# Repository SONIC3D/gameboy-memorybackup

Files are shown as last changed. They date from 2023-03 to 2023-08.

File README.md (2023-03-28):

# Gameboy MemoryBackup Cartridge
## Introduction
This is a gameboy game cartridge save memory backup device. By using this cart, you can transfer the save content from the gameboy cartridge SRAM to the flash memory. So that the data can be preserved without any cell battery.

And additionally, full MBC1 feature has been implemented. So it will support MBC1 games with ROM size no more than 512KB. MBC1 SRAM feature is also supported.

**Please note that the ROM content need to be programmed externally. It's not be able to load ROM content from the plugged-in cartridge in current version.**

## Updates:
* v1.0 (2023.Mar.15)
    * Implemented the basic routing.
* v1.1 (2023.Mar.17)
    * Redesigned the PCB for installing within original GameBoy cartridge shell. because producing 2.0mm PCB will cause unnecessary cost in JLCPCB.
* v1.2 (2023.Mar.17)
    * Captures the /Reset signal to latch the switch button state on power-on.(The original MemoryBackup cartridge has no such feature.)
* v1.3 (2023.Mar.26)
    * Most features of the cartridge hardware are finished. Implemented full MemoryBackup cartridge feature. And additionally, implemented MBC1 feature as addon(With known issue and minor difference).
* v1.4 (WIP)
    * Fixed the known issue in v1.3 and revise the design to make the MBC1 feature completely same as the original(Except the ROM size is limited to not over 512KB/4Mbit).
    * This is the first version I make the order for real PCB production.

## Requirements(v1.4):
* Basic soldering skill. Most components are in Through-Hole type.
* ATMEL JTAG ISP programmer for ATF15xx series.
    * Model number is ATDH1150USB. Digi-Key link: [Here](https://www.digikey.com/en/products/detail/microchip-technology/ATDH1150USB/2050869)
* ATMEL WinCUPL(If you need to modify the PLD source code):
    * [Download Page](https://www.microchip.com/en-us/products/fpgas-and-plds/spld-cplds/pld-design-resources). Please note you need to enter the S/N provided by ATMEL on this page during the installation .
    * [Documentations](https://www.microchip.com/en-us/development-tool/WinCUPL)
* ROM Programmer that support your main program ROM model.
    * For example, if you decide to use a SST 28SF040 or AT29C040 as the program ROM, you can consider [Xeltek Superpro 610p](https://www.xeltek-cn.com/en/universal-programmers/economy-universal-programmer-superpro-610p.html), check the device list to make sure your ROM is supported.
* Components:
    * Mainboard
        * PLCC-44 IC socket x1
        * PLCC-32 IC socket x2
        * DIP-32 IC socket x1
        * DIP-32 IC socket x1
        * CR1616 battery socket x1
        * SPDT Switch(90deg angled) x1
        * 2*16 PinSocket x1
        * 2*5 PinSocket x1(This is for ISP program the ATF15xx CPLD, if you have JTAG cable extender with a fixture, this PinSocket is not needed.)
        * Capacitor 0.1uF x6
        * Resistor 10K x3
        * Resistor 1K x3
        * ATF1502 PLCC44 x1(ATF1504 PLCC44 is also compatible, source code need to be modified)
        * SST 28SF040 PLCC32 Programmable ROM x1 (512KB Storage ROM)
        * 16KB-512KB PLCC32 Programmable ROM x1 (Main Program ROM. SST 28SF040 is also an acceptable model)
        * TC551001 DIP32 Static RAM x1 (Or other pin compatible 128KB/1Mbit Static RAM)
        * BA6162F battery supervisor chip x1
    * Subboard
        * NDSL GBA cartridge slot.(Search and grab one on aliexpress.)
        * 2*16 PinHeader x1

## ROM data for the main program
* I'm still creating my own program to implement the backup feature. But as this cartridge support the original Karat MemoryBackup, which is also known as "Mega Memory" or "Mega Memory Card" in other regions. You can also use the dumped ROM from these products. More Info:
    * [TCRF.NET](https://tcrf.net/Mega_Memory_Card_(Game_Boy))
    * [Manual(Archive.org)](https://archive.org/details/mega-memory-card-gameboy-manual-and-cart-hi-res-ozidual)
    * [ROM(Archive.org), filename "Mega Memory (World) (Unl).7z"](https://archive.org/details/nointro.gb)

## Tech detail on the Mapper Logic implemented in this cartridge(v1.4)
* (WIP)

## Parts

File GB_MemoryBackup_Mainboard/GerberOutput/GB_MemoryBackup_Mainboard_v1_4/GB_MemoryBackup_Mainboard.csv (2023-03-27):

Comment | Designator | Footprint | LCSC
3V | BT1 | Battery_JLCPCB:BAT-SMD_CR1616 | C964732
0.1uF | C1,C2,C3,C4,C5,C7 | Capacitor_SMD:C_0805_2012Metric | C49678
GB_Cart_EdgeConn-1Row-32Pins | J1 | NintendoGBCart_ExtFootprint:GB_Cart_1x32_P1.50mm_Edge_For_CartShell
JTAG-A | J3 | Connector_PinHeader_Boxed_2.54mm:PinHeader_2x05_P2.54mm_Vertical
Conn_02x16_Odd_Even | J4 | Connector_PinSocket_2.54mm:PinSocket_2x16_P2.54mm_Vertical
10K | R1,R11,R12 | Resistor_SMD:R_0805_2012Metric | C17414
1K | R13 | Resistor_SMD:R_0805_2012Metric | C17513
SW_SPDT | SW1 | Button_Switch_THT_JLCPCB:SW-TH_SK12D07VG3 | C431547
AT29C010A-PLCC32 | U1 | Package_LCC_JLCPCB:PLCC-32_THT-Socket | C72257
28SF040-120-4C-NH-PLCC32 | U2 | Package_LCC_JLCPCB:PLCC-32_THT-Socket | C72257
Generic-ATF15xx-PLCC44 | U3 | Package_LCC_JLCPCB:PLCC-44_THT-Socket | C2828044
TC551001BPL_DIP32 | U4 | Package_DIP:DIP-32_W15.24mm_Socket
BA6162F | U5 | Package_SO:SOIC-8_3.9x4.9mm_P1.27mm | C2927697
74HC373 | U7 | Package_DIP:DIP-20_W7.62mm_Socket | C546888

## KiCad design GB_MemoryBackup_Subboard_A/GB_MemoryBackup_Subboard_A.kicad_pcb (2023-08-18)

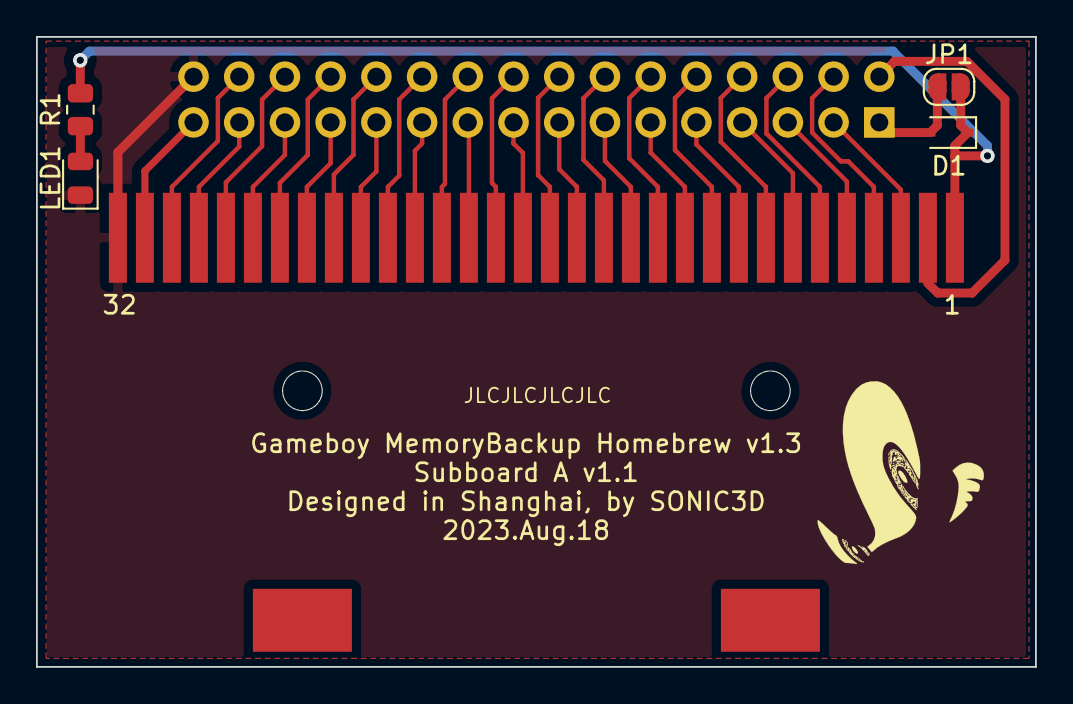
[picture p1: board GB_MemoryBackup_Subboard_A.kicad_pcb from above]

Board: 2 copper layers, 55.5 x 35.0 mm, 6 parts (1 on the bottom side), 34 nets.

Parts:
D1: 1N4148WS; D_SOD-323
J1: Conn_02x16_Odd_Even; PinHeader_2x16_P2.54mm_Vertical
J2: GB_Cart_Slot-1Row-32Pins; GB_GBA_Cartridge_Slot
JP1: SJ_SkipDiode; SolderJumper-2_P1.3mm_Open_RoundedPad1.0x1.5mm
LED1: PowerLED_Red; D_0805_2012Metric
R1: 10K; R_0805_2012Metric

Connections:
+5V: D1.2, J1.1, JP1.1
/AA0: J1.6, J2.6
/AA1: J1.7, J2.7
/AA2: J1.8, J2.8
/AA3: J1.9, J2.9
/AA4: J1.10, J2.10
/AA5: J1.11, J2.11
/AA6: J1.12, J2.12
/AA7: J1.13, J2.13
/AA8: J1.14, J2.14
/AA9: J1.15, J2.15
/AA10: J1.16, J2.16
/AA11: J1.17, J2.17
/AA12: J1.18, J2.18
/AA13: J1.19, J2.19
/AA14: J1.20, J2.20
/AA15_T: J1.21, J2.21
/AAudioIn: J1.31, J2.31
/ACLK: J1.2, J2.2
/AD0: J1.22, J2.22
/AD1: J1.23, J2.23
/AD2: J1.24, J2.24
/AD3: J1.25, J2.25
/AD4: J1.26, J2.26
/AD5: J1.27, J2.27
/AD6: J1.28, J2.28
/AD7: J1.29, J2.29
/CartSlot_5V_Input: D1.1, J2.1, JP1.2, R1.2
/PwrLED_5V_Input: LED1.2, R1.1
/~ARD_T: J1.4, J2.4
/~ARST: J1.30, J2.30
/~ASRAM_CS: J1.5, J2.5
/~AWR_T: J1.3, J2.3
GND: J1.32, J2.32, LED1.1

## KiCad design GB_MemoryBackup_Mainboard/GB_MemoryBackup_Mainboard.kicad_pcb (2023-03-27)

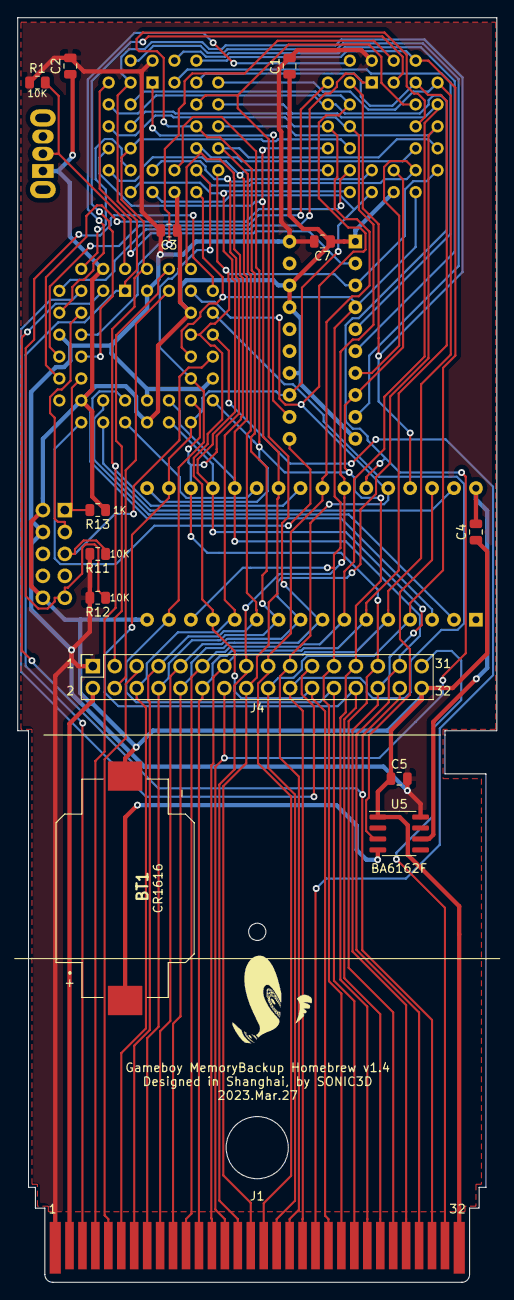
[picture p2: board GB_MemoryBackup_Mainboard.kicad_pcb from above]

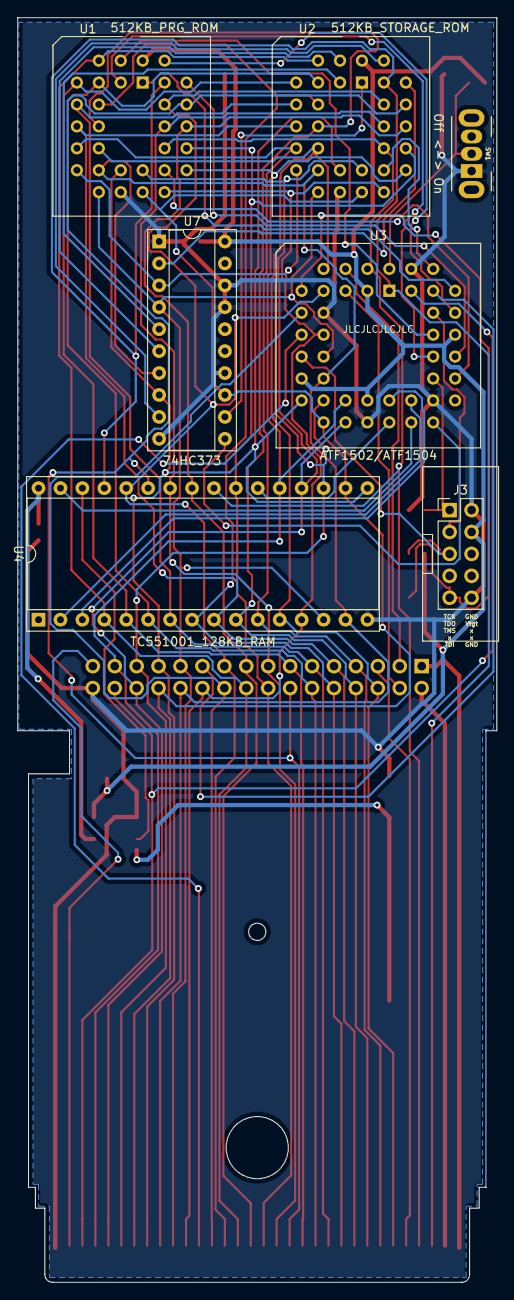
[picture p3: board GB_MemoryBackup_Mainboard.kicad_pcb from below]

Board: 2 copper layers, 55.5 x 146.5 mm, 21 parts (7 on the bottom side), 60 nets.

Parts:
BT1: 3V; BAT-SMD_CR1616
C1, C2, C3, C4, C5, C7: 0.1uF; C_0805_2012Metric
J1: GB_Cart_EdgeConn-1Row-32Pins; GB_Cart_1x32_P1.50mm_Edge_For_CartShell
J3: JTAG-A; PinHeader_2x05_P2.54mm_Vertical
J4: Conn_02x16_Odd_Even; PinSocket_2x16_P2.54mm_Vertical
R1, R11, R12: 10K; R_0805_2012Metric
R13: 1K; R_0805_2012Metric
SW1: SW_SPDT; SW-TH_SK12D07VG3
U1: AT29C010A-PLCC32; PLCC-32_THT-Socket
U2: 28SF040-120-4C-NH-PLCC32; PLCC-32_THT-Socket
U3: Generic-ATF15xx-PLCC44; PLCC-44_THT-Socket
U4: TC551001BPL_DIP32; DIP-32_W15.24mm_Socket
U5: BA6162F; SOIC-8_3.9x4.9mm_P1.27mm
U7: 74HC373; DIP-20_W7.62mm_Socket

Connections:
+5V: C1.2, C2.2, C3.2, C5.2, C7.2, J1.1, J3.4, J4.1, R1.1, R11.2, R12.2, U1.32, U2.32, U3.3, U3.15, U3.23, U3.35, U5.8, U7.20
/AA0: J1.6, J4.6, U1.12, U2.12, U3.6, U4.12
/AA1: J1.7, J4.7, U1.11, U2.11, U4.11
/AA2: J1.8, J4.8, U1.10, U2.10, U4.10
/AA3: J1.9, J4.9, U1.9, U2.9, U4.9
/AA4: J1.10, J4.10, U1.8, U2.8, U4.8
/AA5: J1.11, J4.11, U1.7, U2.7, U4.7
/AA6: J1.12, J4.12, U1.6, U2.6, U4.6
/AA7: J1.13, J4.13, U1.5, U2.5, U4.5
/AA8: J1.14, J4.14, U1.27, U2.27, U4.27
/AA9: J1.15, J4.15, U1.26, U2.26, U4.26
/AA10: J1.16, J4.16, U1.23, U2.23, U4.23
/AA11: J1.17, J4.17, U1.25, U2.25, U4.25
/AA12: J1.18, J4.18, U1.4, U2.4, U4.4
/AA13: J1.19, J4.19, U1.28, U2.28, U3.8, U4.28
/AA14: J1.20, J4.20, U3.9
/AA15: J1.21, U3.11
/AA15_T: J4.21, U3.41
/AAudioIn: J1.31, J4.31
/ACLK: J1.2, J4.2
/AD0: J1.22, J4.22, U1.13, U2.13, U3.12, U4.13, U7.3
/AD1: J1.23, J4.23, U1.14, U2.14, U3.14, U4.14, U7.4
/AD2: J1.24, J4.24, U1.15, U2.15, U3.16, U4.15, U7.7
/AD3: J1.25, J4.25, U1.17, U2.17, U3.17, U4.17, U7.8
/AD4: J1.26, J4.26, U1.18, U2.18, U3.18, U4.18, U7.13
/AD5: J1.27, J4.27, U1.19, U2.19, U3.19, U4.19
/AD6: J1.28, J4.28, U1.20, U2.20, U3.20, U4.20
/AD7: J1.29, J4.29, U1.21, U2.21, U3.21, U4.21
/F010_A14: U1.29, U3.33
/F010_A15: U1.3, U3.34
/F010_A16: U1.2, U3.36
/F010_A17: U1.30, U3.37
/F010_A18: U1.1, U3.39
/F040_A14: U2.29, U7.2
/F040_A15: U2.3, U7.5
/F040_A16: U2.2, U7.6
/F040_A17: U2.30, U7.9
/F040_A18: U2.1, U7.12
/HC373_040_LE: U3.28, U7.11
/RAM_A14: U3.25, U4.3
/RAM_A15: U3.26, U4.31
/RAM_A16: U3.27, U4.2
/RAM_CE2: U4.30, U5.3
/TCK: J3.1, R13.2, U3.32
/TDI: J3.9, R12.1, U3.7
/TDO: J3.3, U3.38
/TMS: J3.5, R11.1, U3.13
/~ARD: J1.4, U1.24, U2.24, U3.2, U4.24
/~ARD_T: J4.4, U3.5
/~ARST: J1.30, J4.30, U3.43
/~ASRAM_CS: J1.5, J4.5
/~AWR: J1.3, U1.31, U2.31, U3.1, U4.29
/~AWR_T: J4.3, U3.4
/~F_CE_010: U1.22, U3.31
/~F_CE_040: U2.22, U3.40
/~RAM_CE: U3.24, U4.22
/~SW_1: R1.2, SW1.2, U3.44
GND: BT1.2, C1.1, C2.1, C3.1, C4.1, C5.1, C7.1, J1.32, J3.2, J3.10, J4.32, R13.1, SW1.1, U1.16, U2.16, U3.10, U3.22, U3.30, U3.42, U4.16, U5.1, U7.1, U7.10, U7.14, U7.17, U7.18
unnamed: BT1.1, U5.4
VMEM: C4.2, U4.32, U5.6

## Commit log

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2023-03-13 Added: Schematic created, added edge connector, slot, CPLD and switch
    [GB_MemoryBackup_Mainboard.sch]
2023-03-13 Added: CPLD JTAG port
    [GB_MemoryBackup_Mainboard.sch]
2023-03-13 Added: Switch button 2 for additional control ability.
    [GB_MemoryBackup_Mainboard.sch]
2023-03-13 Added: The main program ROM AT29C010/020/040 and the save backup storage ROM 28SF040/28SF040A
    [GB_MemoryBackup_Mainboard.sch]
2023-03-13 Added: A lot of notes. CPLD equations and memory maps info.
    [GB_MemoryBackup_Mainboard.sch]
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2023-03-14 Modified: Footprint id for most components.
    [GB_MemoryBackup_Mainboard.sch]
2023-03-14 Modified: PLCC socket component id in JLCPCB.
    [GB_MemoryBackup_Mainboard.sch]
2023-03-14 Added: Preliminary pcb components placement.
    [GB_MemoryBackup_Mainboard.kicad_pcb]
2023-03-14 Modified: Set PLCC-32 chips to use PLCC-32 socket SMD footprint.
    [GB_MemoryBackup_Mainboard.sch]
2023-03-14 Modified: PCB updated with the updated footprints.
    [GB_MemoryBackup_Mainboard.kicad_pcb]
2023-03-14 Modified: PCB design updated
    [GB_MemoryBackup_Mainboard.kicad_pcb]
2023-03-14 Modified: Edge footprint has been changed.
    [GB_MemoryBackup_Mainboard.sch]
2023-03-14 Modified: PCB design updated using Raw PCB setting.
    [GB_MemoryBackup_Mainboard.kicad_pcb]
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2023-03-14 Modified: More keepout areas.
    [GB_MemoryBackup_Mainboard.kicad_pcb]
2023-03-14 Modified: Auto routed and manually revised.
    [GB_MemoryBackup_Mainboard.kicad_pcb]
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2023-03-14 Modified: Added copper filled zone. Modified: Added Logo and info text on PCB.
    [GB_MemoryBackup_Mainboard.kicad_pcb]
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2023-03-14 Modified: Set the gerber output settings.
    [GB_MemoryBackup_Mainboard.kicad_pcb]
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2023-03-14 Added: PCB v1.0 gerber files and pos files.
    [GB_MemoryBackup_Mainboard-B_Cu.gbl, GB_MemoryBackup_Mainboard-B_Mask.gbs, GB_MemoryBackup_Mainboard-B_Paste.gbp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]
2023-03-14 Modified: POS file column title changed along to the JLCPCB standard.
    [GB_MemoryBackup_Mainboard-bottom-pos.csv, GB_MemoryBackup_Mainboard-top-pos.csv]
2023-03-14 Modified: PCB redesigned for using with plastic cart shell.
    [GB_MemoryBackup_Mainboard.kicad_pcb]
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2023-03-14 Modified: Moved PLCC-44 IC socket for the cartridge shell hole.
    [GB_MemoryBackup_Mainboard.kicad_pcb]
2023-03-14 Modified: Changed info text layer for auto routing.
    [GB_MemoryBackup_Mainboard.kicad_pcb]
2023-03-15 Modified: Added copper filled zone. Modified: PCB version updated to v1.1.
    [GB_MemoryBackup_Mainboard.kicad_pcb]
2023-03-15 Modified: PLCC-32 IC socket footprint updated from library.
    [GB_MemoryBackup_Mainboard.kicad_pcb]
2023-03-16 Modified: Equation logic on schematic sheet.
    [GB_MemoryBackup_Mainboard.sch]
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2023-03-16 Modified: v1.1 pcb gerber exported.
    [GB_MemoryBackup_Mainboard.kicad_pcb]
2023-03-16 Modified: v1.1 pos file.(JLCPCB format.)
    [GB_MemoryBackup_Mainboard-all-pos.csv]
2023-03-16 Modified: Commented push button and the pull-up resistor. Free the CPLD pin for connecting the /RST signal from cartridge slot.(For implement the latching of the switch button state value on power-on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
    [GB_MemoryBackup_Mainboard.sch]
2023-03-16 Modified: Slightly modified the routing, syncing to the changes of the schematic.
    [GB_MemoryBackup_Mainboard.kicad_pcb]
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2023-03-17 Modified: v1.2 pcb gerber exported.
    [GB_MemoryBackup_Mainboard.kicad_pcb]
2023-03-17 Modified: v1.2 pos file.
    [GB_MemoryBackup_Mainboard-all-pos.csv]
2023-03-17 Modified: v1.2 pos file.(JLCPCB format.)
    [GB_MemoryBackup_Mainboard-all-pos.csv]
2023-03-17 Modified: v1.2 BOM copied to gerber output directory.
    [GB_MemoryBackup_Mainboard.csv]
2023-03-18 Modified: Added 128KB SRAM and cell battery for implementing the full MBC1 save RAM support in future. Modified: Used 2 external 74HC373 for latching the high address line for main program ROM and st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
    [GB_MemoryBackup_Mainboard.sch]
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2023-03-18 Modified: Footprints and JLCPCB component id.
    [GB_MemoryBackup_Mainboard.sch]
2023-03-18 Modified: Use THT socket for PLCC-32 and PLCC-44 IC, for easier soldering by hand.
    [GB_MemoryBackup_Mainboard.sch]
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2023-03-18 Modified: PCB components position modified for easier track routing.
    [GB_MemoryBackup_Mainboard.kicad_pcb]
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2023-03-19 Modified: PCB routed and manually revised. Modified: Added all info text labels on silk layers.
    [GB_MemoryBackup_Mainboard.kicad_pcb]
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2023-03-19 Modified: v1.3 BOM copied to gerber output directory.
    [GB_MemoryBackup_Mainboard.csv]
2023-03-20 Modified: Swapped SW_1 and SW_2/ARST. For connecting /ARST to Global clk line, saving the product expression resource.
    [GB_MemoryBackup_Mainboard.sch]
2023-03-20 Modified: Swapped SW_1 and SW_2/ARST on PCB project.
    [GB_MemoryBackup_Mainboard.kicad_pcb]
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2023-03-20 Modified: RAM need 8KB banking, so schematic is changed from banking through RAM_A16..A14 to RAM_A15..A13, and hold the A16 to always high.
    [GB_MemoryBackup_Mainboard.sch]
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2023-03-24 Revert "Modified: v1.3 pcb gerber re-exported."
    This reverts commit 0760941d7047ae5b69f201c7affc4bef0eac5c75.
    [GB_MemoryBackup_Mainboard-B_Cu.gbl, GB_MemoryBackup_Mainboard-B_Mask.gbs, GB_MemoryBackup_Mainboard-B_Paste.gbp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]
2023-03-24 Revert "Modified: PCB modified based on the schematic."
    This reverts commit fa85ecb86ebcad4c6abd318417a0d0b5febaa9af.
    [GB_MemoryBackup_Mainboard.kicad_pcb]
2023-03-24 Revert "Modified: RAM need 8KB banking, so schematic is changed from banking through RAM_A16..A14 to RAM_A15..A13, and hold the A16 to always high."
    This reverts commit b47ffc313482a9c34a73032e10e4ca5aa5a3d764.
    [GB_MemoryBackup_Mainboard.sch]
2023-03-26 Modified: v1.4 schematic. Hide the 74HC373 for PRG ROM banking. And integrate the banking logic to CPLD.
    [GB_MemoryBackup_Mainboard.sch]
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2023-03-27 Modified: v1.4 BOM copied to gerber output directory.
    [GB_MemoryBackup_Mainboard.csv]
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2023-03-27 Modified: Info text on PCB silk and mask layers.
    [GB_MemoryBackup_Mainboard.kicad_pcb]
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2023-04-09 Fixed: It seems on falling edge of /WR signal, the address bus is ready, bu the data bus may not be ready all the times. It makes writing $80 to $2000 sometimes not switch the PrimaryMode_G0 to 0. So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
2023-08-18 Modified: SubBoard v1.1. Added diode, diode skipping solderjumper, and power indication led.
    [GB_MemoryBackup_Subboard_A.kicad_pcb, GB_MemoryBackup_Subboard_A.sch]
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
